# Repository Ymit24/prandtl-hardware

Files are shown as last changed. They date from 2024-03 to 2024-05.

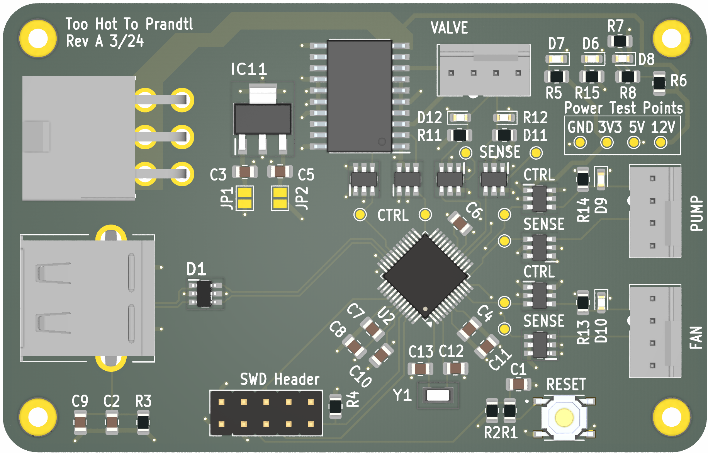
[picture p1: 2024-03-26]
pictures/ray_ortho_home_no_shadows.png

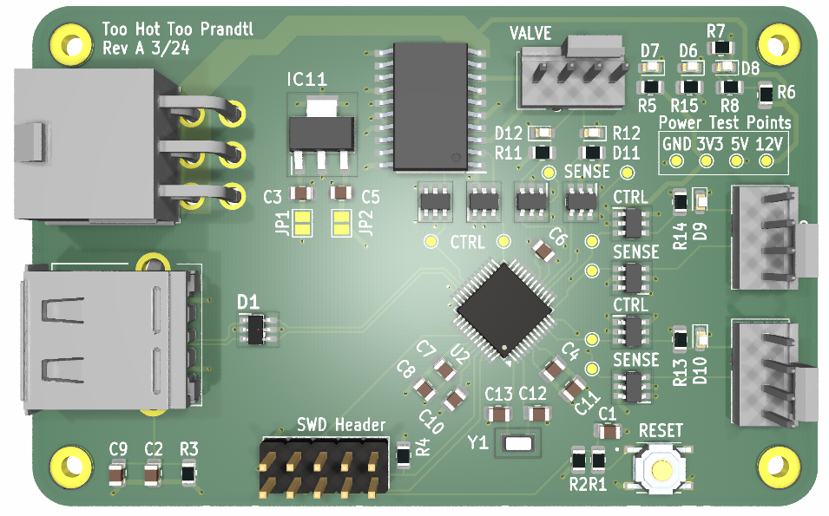
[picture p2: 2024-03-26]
pictures/raw_persp_home.png

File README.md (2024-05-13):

# ❄️🎛️ Too Hot To Prandtl Hardware

## About this repo
This repo contains all the hardware I designed for my undergraduate senior design project "Too Hot To Prandtl".

<!-- TABLE OF CONTENTS -->
<div>
  <h4>Table of Contents</h4>
  <ol>
    <li>
      <a href="#about-the-project">About The Project</a>
      <ul>
        <li><a href="#built-with">Built With</a></li>
      </ul>
    </li>
    <li><a href="#roadmap">Roadmap</a></li>
    <li><a href="#license">License</a></li>
    <li><a href="#contact">Contact</a></li>
  </ol>
</div>

## About the Project
My senior design project, "Too hot to prandtl", is a thermal management solution designed for heterogeniously packaged chips.
It is a fluid based cooler which leverages phase change to increase heat transfer.
Myself, along with four Mechnical Engineering students designed, simulated, fabricated, and tested this system.
As the teams sole Electrical Engineer, I wrote all the software and designed, ordered, assembled, and brought-up the custom embedded system's printed circuit board (PCB).
The software for this project is hosted in a seperate repository found [here](https://github.com/Ymit24/too-hot-to-prandtl-control-system/tree/main).



## Project Structure
This system is designed in KiCad. Any non-default symbols/footprints/models are located in the `lib/` directory and included in the custom symbols and footprints libraries.
Production files which were used for the prototype system are in the `production/` directory.

### Built With
- [KiCad](https://www.kicad.org), awesome free PCB designing tool!

## Roadmap
There are several design flaws in the first version of this system, all of which were able to be fixed in the lab so that the board was still operable.
Below are a few issues which I would address in a revision B, ordered from most severe to least.

- ESD protection diode is connected incorrectly. I misread the data sheet and connected the channels incorrectly.
- Serial wire debug header is both the wrong size/type and the footprint had a different pin labelling scheme than intended.
- Fan peripheral header needs power and ground connection.
- Use a single 8-bit/channel logic level shifter rather than eight individual 1-bit/channel shifters.
- Choose dimmer LEDs, the ones choosen are very bright.
- Fix typo in silkscreen for board name "Too Hot Too Prandtl" -> "Too Hot To Prandtl".

## License
This project uses the GNU General Purpose License (GPL). Basically, do whatever you want but you must open source any derivative work!

## Contact
My name is Christian Smith and you can contact me through my linked in [here](https://www.linkedin.com/in/christian-ryan-smith/).
As this was a senior design project which has now concluded, further work and support of this project will not continue.

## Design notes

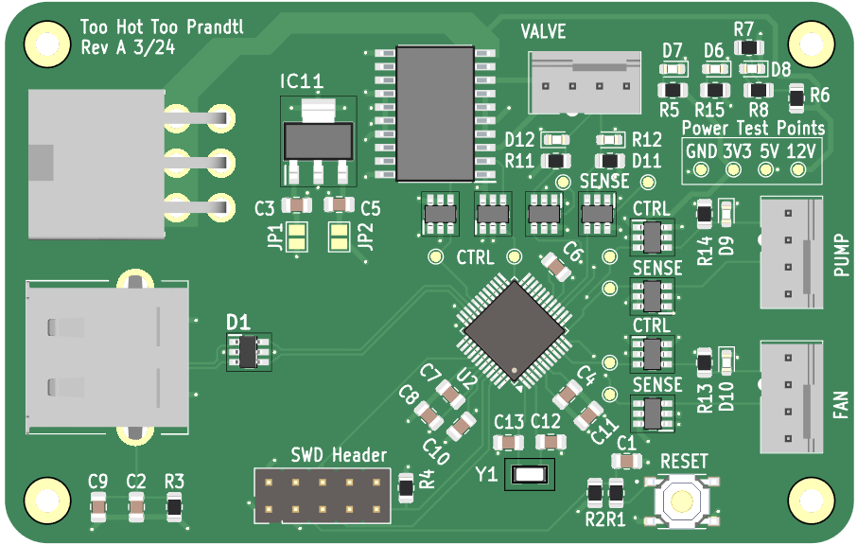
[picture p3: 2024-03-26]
pictures/style_ortho_home.png

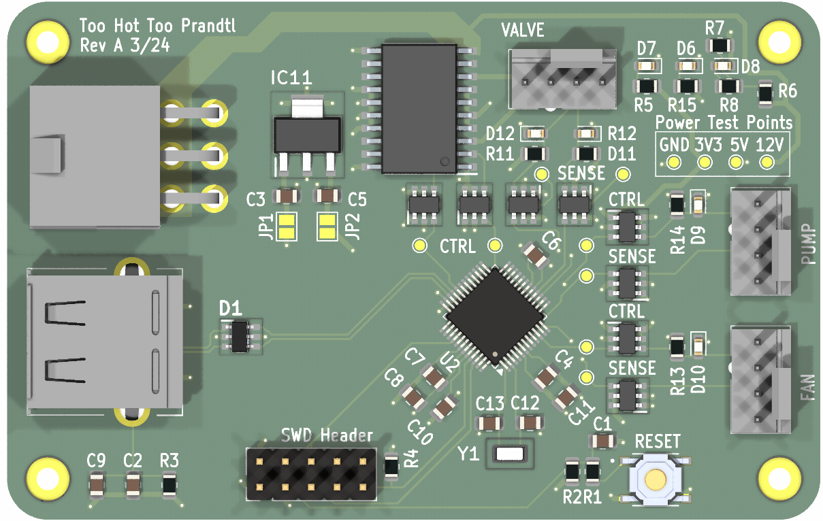
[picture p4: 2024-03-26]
pictures/ray_ortho_home_new.png

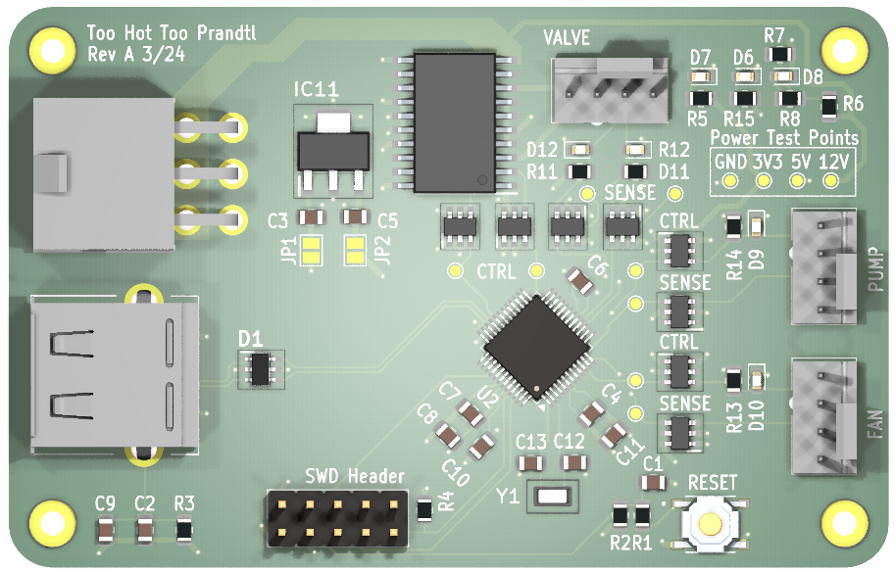
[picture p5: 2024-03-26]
pictures/ray_ortho_home.png

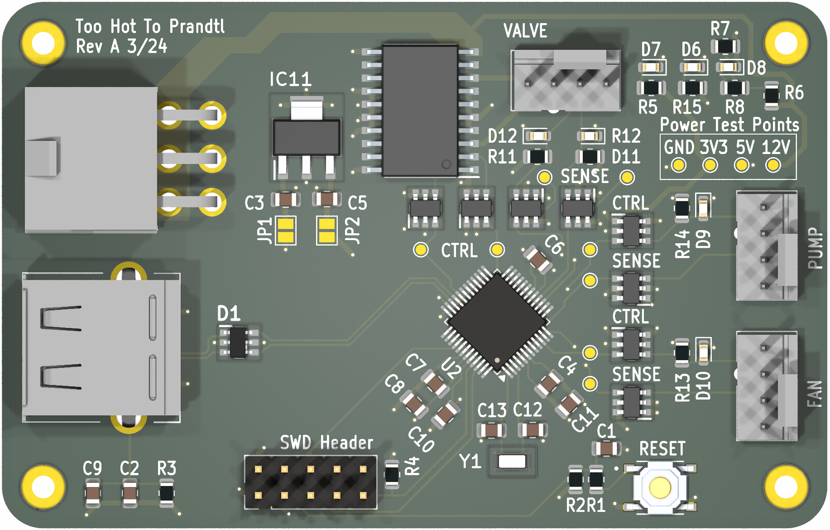
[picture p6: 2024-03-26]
pictures/ray_ortho_home_shadows.png

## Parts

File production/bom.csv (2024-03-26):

Designator | Footprint | Quantity | Value | LCSC Part #
C1, C4, C6, C7 | 0805 | 4 | 100n | C49678
C10, C11 | 0805 | 2 | 10u | C15850
C12, C13 | 0805 | 2 | 20p | C105173
C2, C9 | 0805 | 2 | 2.2n | C28260
C3 | 0805 | 1 | 470n | C13967
C5 | 0805 | 1 | 47u | C16780
C8 | 0805 | 1 | 1u | C307362
D1 | SOP95P275X110-6N | 1 | IP4234CZ6,125 | C455086
D10 | 0603 | 1 | FAN_PWM_IND | C2297
D11 | 0603 | 1 | VALVE_OPEN_IND | C2296
D12 | 0603 | 1 | VALVE_CLOSED_IND | C2296
D6 | 0603 | 1 | 5V_USB_PWR_IND | C2286
D7 | 0603 | 1 | 3v3_PWR_IND | C2286
D8 | 0603 | 1 | 12v_PWR_IND | C2286
D9 | 0603 | 1 | PUMP_PWM_IND | C2297
IC11 | SOT230P700X180-4N | 1 | LM3940IMP-3.3_NOPB | C140319
R1 | 0805 | 1 | 330 | C17630
R11, R12, R13, R14, R15 | 0805 | 5 | 200R | C17540
R2 | 0805 | 1 | 10k | C17414
R3 | 0805 | 1 | 1M | C17514
R4 | 0805 | 1 | 1k | C17513
R5 | 0805 | 1 | 51R | C17738
R6, R7 | 0805 | 2 | 470R | C17738
R8 | 0805 | 1 | 300R | C17617
S1 | SW_TS-1187A-B-A-B | 1 | TS-1187A-B-A-B | C318884
U2 | TQFP-48_7x7mm_P0.5mm | 1 | ATSAMD21G18A-A | C78624
Y1 | FC135327680KAA5 | 1 | 32.768kHz | C32346

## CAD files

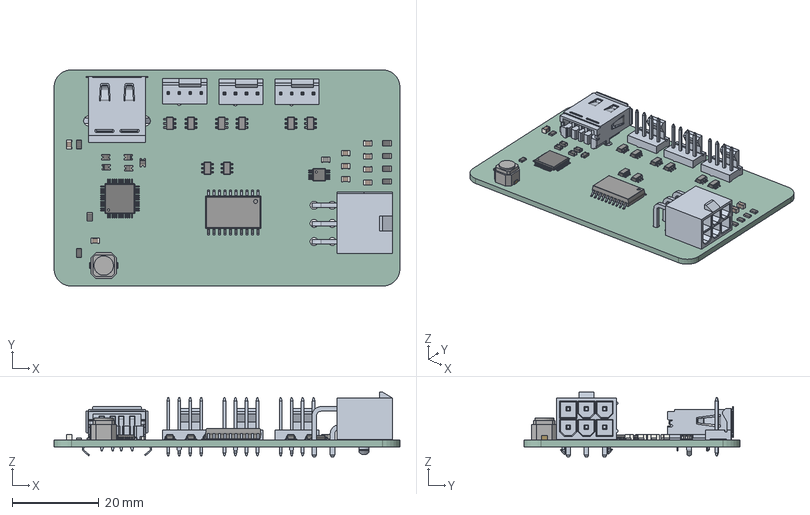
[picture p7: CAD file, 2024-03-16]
playground.step
80.0 x 50.0 x 15.0 mm
LinkGroup
R_0805_2012Metric x 7
C_0805_2012Metric x 9
TQFP_48_7x7mm_P05mm
DBV0006A_ASM x 8
L_0805_2012Metric
D_0805 x 5
ASSEMBLY
MSOP_10_3x3mm_P05mm
playground_PCB

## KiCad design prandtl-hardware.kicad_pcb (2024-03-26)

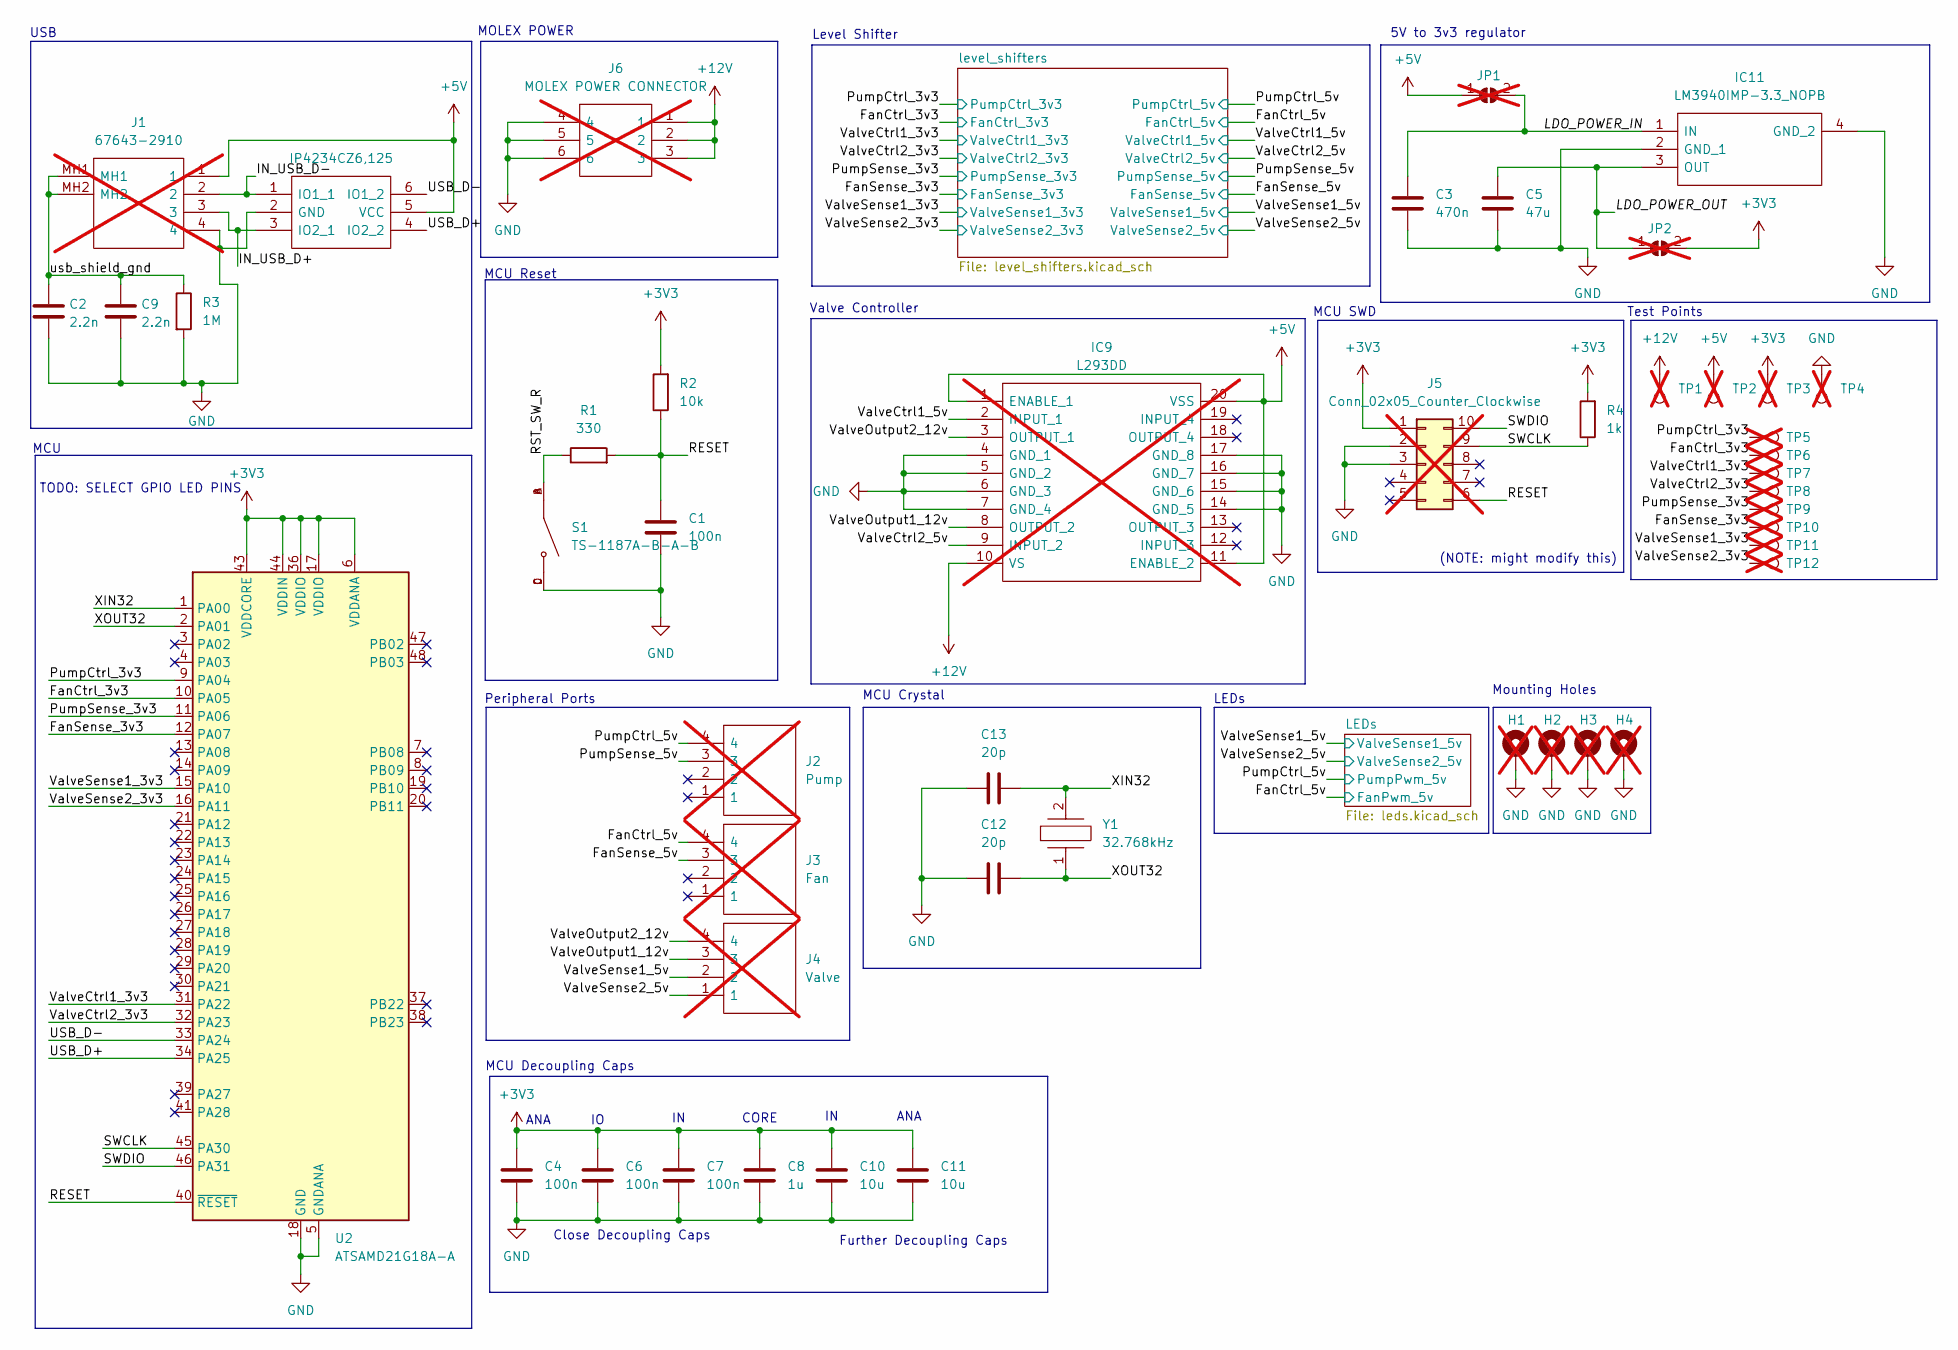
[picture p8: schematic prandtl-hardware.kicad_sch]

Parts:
C1, C4, C6, C7: 100n; C_0805_2012Metric; LCSC C49678
C2, C9: 2.2n; C_0805_2012Metric; LCSC C28260
C3: 470n; C_0805_2012Metric; LCSC C13967
C5: 47u; C_0805_2012Metric; LCSC C16780
C8: 1u; C_0805_2012Metric; LCSC C307362
C10, C11: 10u; C_0805_2012Metric; LCSC C15850
C12, C13: 20p; C_0805_2012Metric; LCSC C105173
D1: IP4234CZ6,125; SOP95P275X110-6N; Mouser Part Number 771-IP4234CZ6125
H1, H2, H3, H4: MountingHole_Pad; MountingHole_2.2mm_M2_Pad; not fitted
IC9: L293DD; SOIC127P1032X265-20N; Mouser Part Number 511-L293DD; not fitted
IC11: LM3940IMP-3.3_NOPB; SOT230P700X180-4N; Mouser Part Number 926-LM3940IMP3.3NOPB
J1: 67643-2910; 676432910; Mouser Part Number 538-67643-2910; not fitted
J2: Pump; 470531000; Mouser Part Number 538-47053-1000; not fitted
J3: Fan; 470531000; Mouser Part Number 538-47053-1000; not fitted
J4: Valve; 470531000; Mouser Part Number 538-47053-1000; not fitted
J5: Conn_02x05_Counter_Clockwise; PinHeader_2x05_P2.54mm_Vertical; not fitted
J6: MOLEX POWER CONNECTOR; 455580003; Mouser Part Number 538-45558-0003; not fitted
JP1, JP2: SolderJumper_2_Open; SolderJumper-2_P1.3mm_Open_Pad1.0x1.5mm; not fitted
R1: 330; R_0805_2012Metric; LCSC C17630
R2: 10k; R_0805_2012Metric; LCSC C17414
R3: 1M; R_0805_2012Metric; LCSC C17514
R4: 1k; R_0805_2012Metric; LCSC C17513
S1: TS-1187A-B-A-B; SW_TS-1187A-B-A-B; PARTREV A0; LCSC C318884
TP1, TP2, TP3, TP4, TP5, TP6, TP7, TP8, TP9, TP10, TP11, TP12: TestPoint; TestPoint_Pad_D1.0mm; not fitted
U2: ATSAMD21G18A-A; TQFP-48_7x7mm_P0.5mm; LCSC C78624
Y1: 32.768kHz; FC135327680KAA5; Mouser Part Number 732-532.7680KA-A5

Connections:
+3V3: C4.1, C6.1, C7.1, C8.1, C10.1, C11.1, J5.1, JP2.2 (B), R2.2, R4.2, TP3.1, U2.6 (VDDANA), U2.17 (VDDIO), U2.36 (VDDIO), U2.43 (VDDCORE), U2.44 (VDDIN); also elsewhere on the board
+5V: D1.5 (VCC), IC9.1 (ENABLE_1), IC9.11 (ENABLE_2), IC9.20 (VSS), J1.1, JP1.1 (A), TP2.1; also elsewhere on the board
+12V: IC9.10 (VS), J6.1, J6.2, J6.3, TP1.1; also elsewhere on the board
/FanCtrl_3v3: TP6.1, U2.10 (PA05); also elsewhere on the board
/FanCtrl_5v: J3.4; also elsewhere on the board
/FanSense_3v3: TP10.1, U2.12 (PA07); also elsewhere on the board
/FanSense_5v: J3.3; also elsewhere on the board
/IN_USB_D+: D1.3 (IO2_1), J1.3
/IN_USB_D-: D1.1 (IO1_1), J1.2
/LDO_POWER_IN: C3.1, IC11.1 (IN), JP1.2 (B)
/LDO_POWER_OUT: C5.1, IC11.3 (OUT), JP2.1 (A)
/PumpCtrl_3v3: TP5.1, U2.9 (PA04); also elsewhere on the board
/PumpCtrl_5v: J2.4; also elsewhere on the board
/PumpSense_3v3: TP9.1, U2.11 (PA06); also elsewhere on the board
/PumpSense_5v: J2.3; also elsewhere on the board
/RESET: C1.1, J5.6, R1.2, R2.1, U2.40 (~RESET)
/RST_SW_R: R1.1, S1.A, S1.B
/SWCLK: J5.9, R4.1, U2.45 (PA30)
/SWDIO: J5.10, U2.46 (PA31)
/USB_D+: D1.4 (IO2_2), U2.34 (PA25)
/USB_D-: D1.6 (IO1_2), U2.33 (PA24)
/ValveCtrl1_3v3: TP7.1, U2.31 (PA22); also elsewhere on the board
/ValveCtrl1_5v: IC9.2 (INPUT_1); also elsewhere on the board
/ValveCtrl2_3v3: TP8.1, U2.32 (PA23); also elsewhere on the board
/ValveCtrl2_5v: IC9.9 (INPUT_2); also elsewhere on the board
/ValveOutput1_12v: IC9.8 (OUTPUT_2), J4.3
/ValveOutput2_12v: IC9.3 (OUTPUT_1), J4.4
/ValveSense1_3v3: TP11.1, U2.15 (PA10); also elsewhere on the board
/ValveSense1_5v: J4.2; also elsewhere on the board
/ValveSense2_3v3: TP12.1, U2.16 (PA11); also elsewhere on the board
/ValveSense2_5v: J4.1; also elsewhere on the board
/XIN32: C13.2, U2.1 (PA00), Y1.2
/XOUT32: C12.2, U2.2 (PA01), Y1.1
/usb_shield_gnd: C2.1, C9.1, J1.MH1, J1.MH2, R3.1
GND: C1.2, C2.2, C3.2, C4.2, C5.2, C6.2, C7.2, C8.2, C9.2, C10.2, C11.2, C12.1, C13.1, D1.2 (GND), H1.1, H2.1, H3.1, H4.1, IC9.4 (GND_1), IC9.5 (GND_2), IC9.6 (GND_3), IC9.7 (GND_4), IC9.14 (GND_5), IC9.15 (GND_6), IC9.16 (GND_7), IC9.17 (GND_8), IC11.2 (GND_1), IC11.4 (GND_2), J1.4, J5.2, J5.3, J6.4, J6.5, J6.6, R3.2, S1.C, S1.D, TP4.1, U2.5 (GNDANA), U2.18 (GND), U2.35 (GND), U2.42 (GND); also elsewhere on the board

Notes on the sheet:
LEDs
Valve Controller
MCU Reset
Close Decoupling Caps
ANA
MOLEX POWER
TODO: SELECT GPIO LED PINS
MCU Decoupling Caps
Further Decoupling Caps
MCU Crystal
5V to 3v3 regulator
Mounting Holes
(NOTE: might modify this)
MCU SWD
USB
MCU
Level Shifter
Peripheral Ports
Test Points
CORE

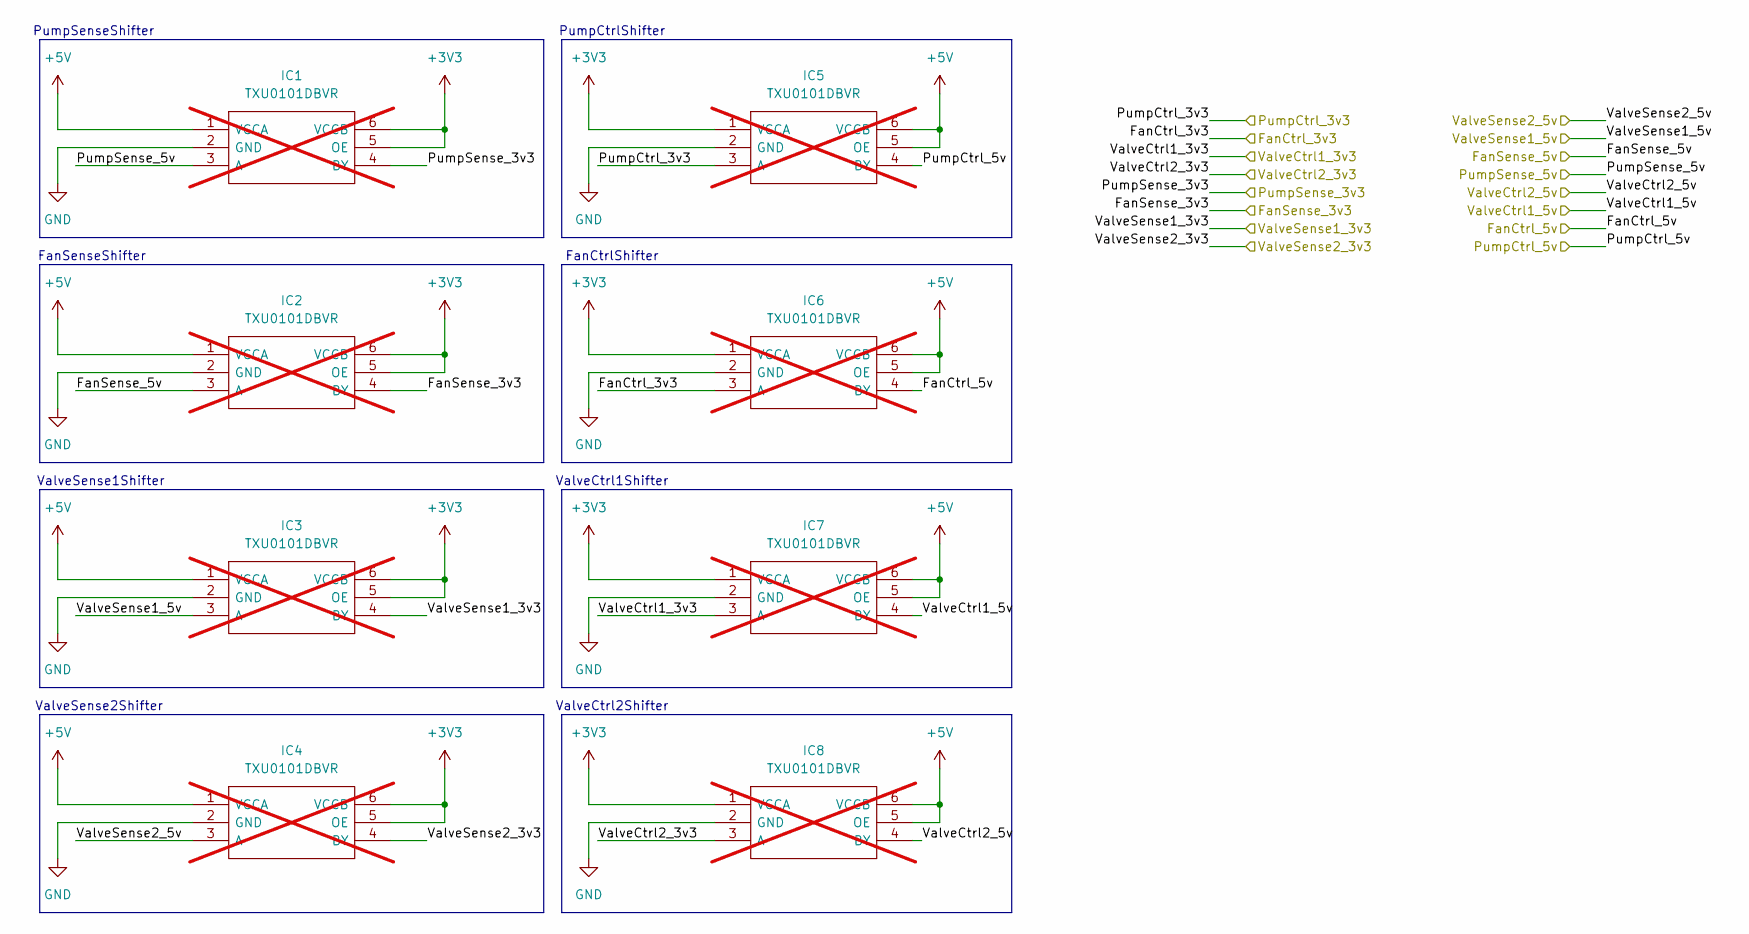
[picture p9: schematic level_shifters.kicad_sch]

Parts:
IC1, IC2, IC3, IC4, IC5, IC6, IC7, IC8: TXU0101DBVR; Mouser Part Number 595-TXU0101DBVR; not fitted

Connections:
+3V3: IC1.5 (OE), IC1.6 (VCCB), IC2.5 (OE), IC2.6 (VCCB), IC3.5 (OE), IC3.6 (VCCB), IC4.5 (OE), IC4.6 (VCCB), IC5.1 (VCCA), IC6.1 (VCCA), IC7.1 (VCCA), IC8.1 (VCCA); also elsewhere on the board
+5V: IC1.1 (VCCA), IC2.1 (VCCA), IC3.1 (VCCA), IC4.1 (VCCA), IC5.5 (OE), IC5.6 (VCCB), IC6.5 (OE), IC6.6 (VCCB), IC7.5 (OE), IC7.6 (VCCB), IC8.5 (OE), IC8.6 (VCCB); also elsewhere on the board
/FanCtrl_3v3: IC6.3 (A); also elsewhere on the board
/FanCtrl_5v: IC6.4 (BY); also elsewhere on the board
/FanSense_3v3: IC2.4 (BY); also elsewhere on the board
/FanSense_5v: IC2.3 (A); also elsewhere on the board
/PumpCtrl_3v3: IC5.3 (A); also elsewhere on the board
/PumpCtrl_5v: IC5.4 (BY); also elsewhere on the board
/PumpSense_3v3: IC1.4 (BY); also elsewhere on the board
/PumpSense_5v: IC1.3 (A); also elsewhere on the board
/ValveCtrl1_3v3: IC7.3 (A); also elsewhere on the board
/ValveCtrl1_5v: IC7.4 (BY); also elsewhere on the board
/ValveCtrl2_3v3: IC8.3 (A); also elsewhere on the board
/ValveCtrl2_5v: IC8.4 (BY); also elsewhere on the board
/ValveSense1_3v3: IC3.4 (BY); also elsewhere on the board
/ValveSense1_5v: IC3.3 (A); also elsewhere on the board
/ValveSense2_3v3: IC4.4 (BY); also elsewhere on the board
/ValveSense2_5v: IC4.3 (A); also elsewhere on the board
GND: IC1.2 (GND), IC2.2 (GND), IC3.2 (GND), IC4.2 (GND), IC5.2 (GND), IC6.2 (GND), IC7.2 (GND), IC8.2 (GND); also elsewhere on the board

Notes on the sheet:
ValveSense1Shifter
PumpCtrlShifter
ValveCtrl2Shifter
ValveSense2Shifter
FanCtrlShifter
PumpSenseShifter
ValveCtrl1Shifter
FanSenseShifter

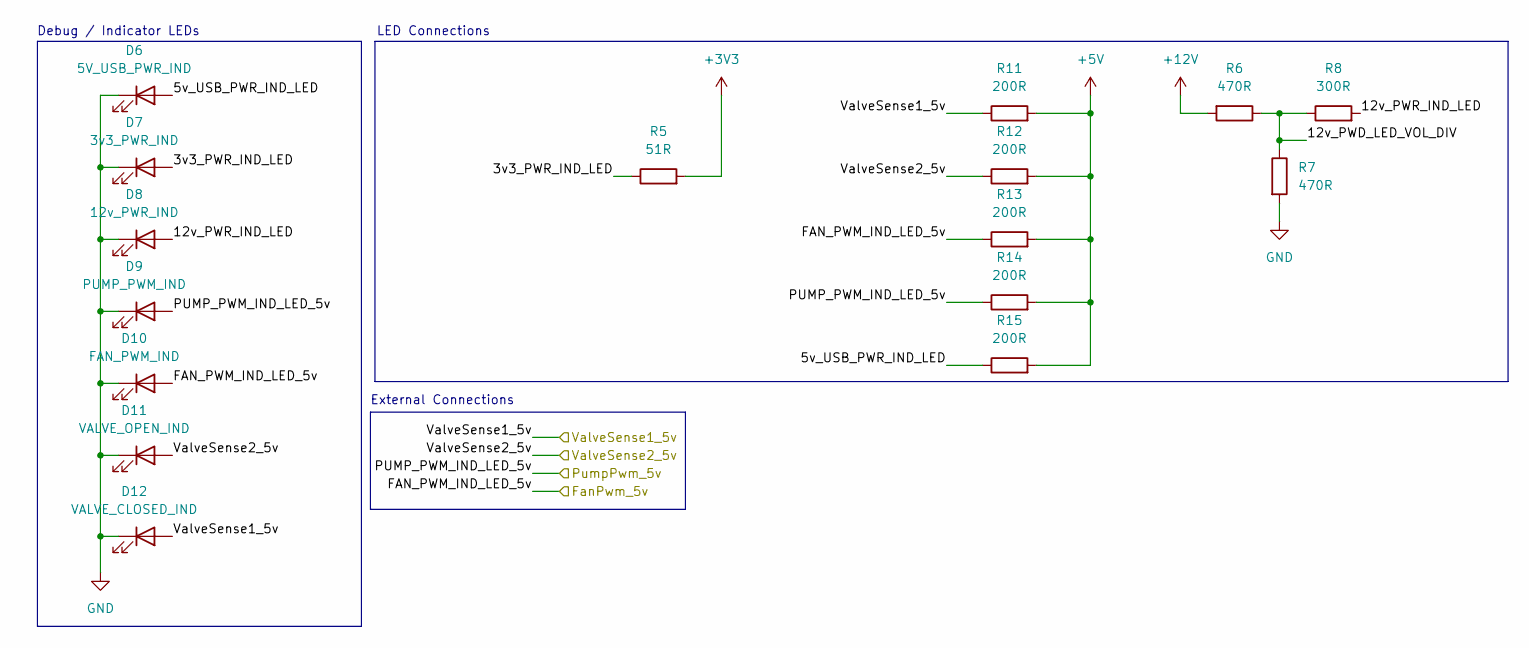
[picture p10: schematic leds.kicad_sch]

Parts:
D6: 5V_USB_PWR_IND; LED_0603_1608Metric; LCSC C2286
D7: 3v3_PWR_IND; LED_0603_1608Metric; LCSC C2286
D8: 12v_PWR_IND; LED_0603_1608Metric; LCSC C2286
D9: PUMP_PWM_IND; LED_0603_1608Metric; LCSC C2297
D10: FAN_PWM_IND; LED_0603_1608Metric; LCSC C2297
D11: VALVE_OPEN_IND; LED_0603_1608Metric; LCSC C2296
D12: VALVE_CLOSED_IND; LED_0603_1608Metric; LCSC C2296
R5: 51R; R_0805_2012Metric; MFR.Part # 0805W8F510JT5E; LCSC C17738
R6: 470R; R_0805_2012Metric; MFR.Part # 0805W8F4700T5E; LCSC C17738
R7: 470R; R_0805_2012Metric; LCSC C17738
R8: 300R; R_0805_2012Metric; MFR.Part # 1206W4F3000T5E; LCSC C17617
R11, R12, R13, R14, R15: 200R; R_0805_2012Metric; MFR.Part # 0805W8F200JT5E; LCSC C17540

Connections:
+3V3: R5.2; also elsewhere on the board
+5V: R11.2, R12.2, R13.2, R14.2, R15.2; also elsewhere on the board
+12V: R6.2; also elsewhere on the board
/FanCtrl_5v: D10.2 (A), R13.1; also elsewhere on the board
/LEDs/3v3_PWR_IND_LED: D7.2 (A), R5.1
/LEDs/5v_USB_PWR_IND_LED: D6.2 (A), R15.1
/LEDs/12v_PWD_LED_VOL_DIV: R6.1, R7.1, R8.1
/LEDs/12v_PWR_IND_LED: D8.2 (A), R8.2
/PumpCtrl_5v: D9.2 (A), R14.1; also elsewhere on the board
/ValveSense1_5v: D12.2 (A), R11.1; also elsewhere on the board
/ValveSense2_5v: D11.2 (A), R12.1; also elsewhere on the board
GND: D6.1 (K), D7.1 (K), D8.1 (K), D9.1 (K), D10.1 (K), D11.1 (K), D12.1 (K), R7.2; also elsewhere on the board

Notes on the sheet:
Debug / Indicator LEDs
External Connections
LED Connections

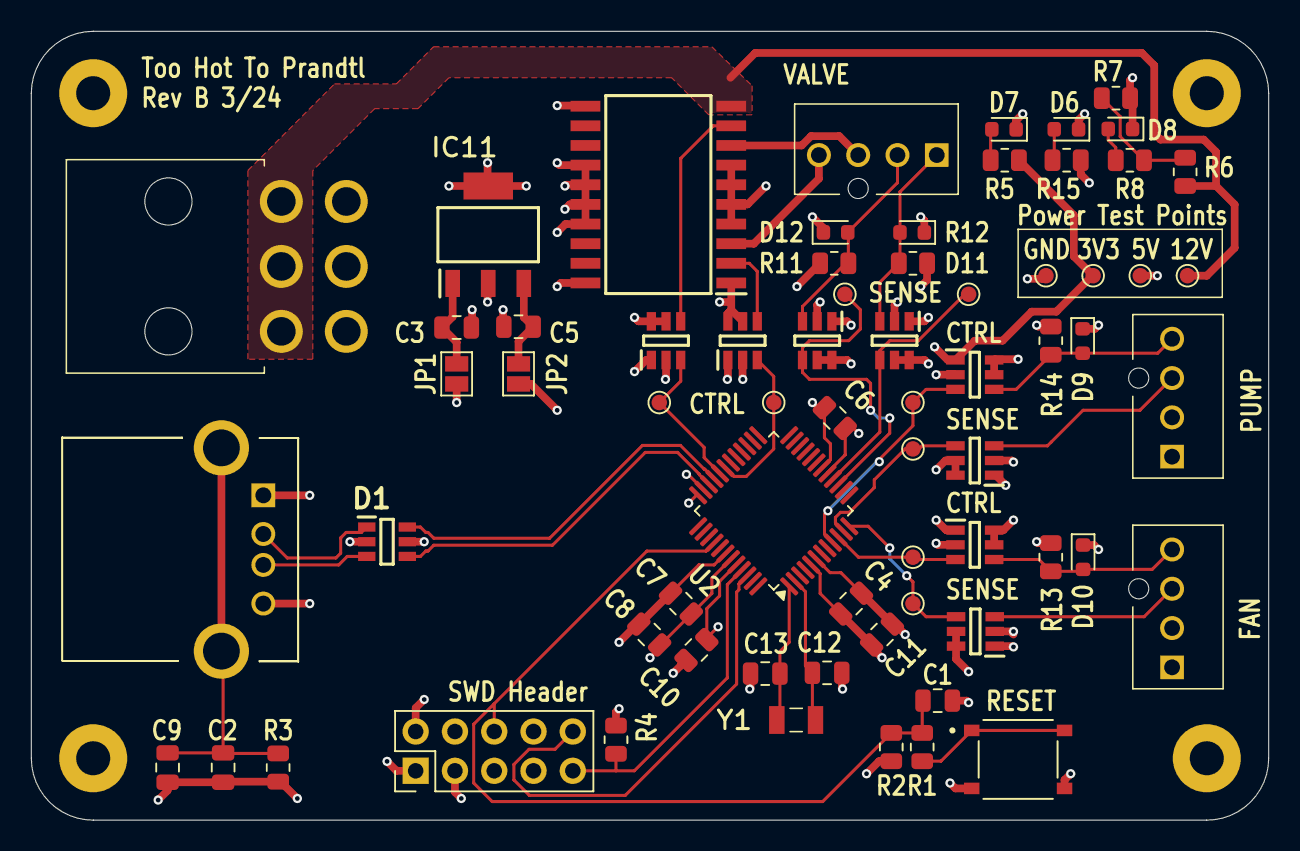
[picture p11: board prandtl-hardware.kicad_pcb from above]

Board: 4 copper layers, 80.0 x 51.0 mm, 71 parts (0 on the bottom side), 39 nets.

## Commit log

2024-02-25 did basic routing. Still missing some parts.
    [playground.kicad_pcb, playground.kicad_sch]
2024-03-16 storing local changes.
    [playground.step]
2024-03-20 saving progress
    [BOM-playground.csv, level_shifters.kicad_sch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]
2024-03-20 Added LEDs and testpoints
    [leds.kicad_sch, playground.kicad_pcb, playground.kicad_sch]
2024-03-21 removed jumpers
    [playground.kicad_pcb, playground.kicad_sch]
2024-03-21 Changed board size to 80x80mm
    [playground.kicad_pcb]
2024-03-22 Updated layout and schem
    [leds.kicad_sch, playground.kicad_pcb, playground.kicad_sch]
2024-03-23 Layout of indicator LEDs. Shrank design space
    [leds.kicad_sch, playground.kicad_pcb, playground.kicad_sch]
2024-03-23 Reduced board size
    [playground.kicad_pcb]
2024-03-23 Initial Routing
    [playground.kicad_pcb]
2024-03-23 Completed intial 2-layer routing.
    [playground.kicad_pcb]
2024-03-23 Initial Layout
    [leds.kicad_sch, playground.kicad_pcb, playground.kicad_sch]
2024-03-23 Fixed board outline
    [playground.kicad_pcb]
2024-03-24 Layout and Route of 4 layer version complete.
    [playground.kicad_pcb, playground.kicad_sch]
2024-03-24 Modified layout. Added more silkscreen.
    [playground.kicad_pcb, playground.kicad_sch]
2024-03-24 Fixed all DRC issues
    [playground.kicad_pcb]
2024-03-24 Small part substitutions. Working on BOM
    [bom.csv, designators.csv, playground.kicad_pcb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]
2024-03-26 Added all part numbers
    [leds.kicad_sch, playground.kicad_pcb, playground.kicad_sch]
2024-03-26 Prepped for production.
    [bom.csv, designators.csv, level_shifters.kicad_sch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]
2024-03-26 Version exported for production.
    [playground.kicad_pcb, positions.csv]
2024-03-26 Took pictures of PCB
    [playground.kicad_pcb]
2024-03-26 Cleaned up project files
    [bom.csv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]
2024-03-26 Fixed spelling of 'Too hot _to_ prandtl'. Now rev B
    [playground.kicad_pcb]
2024-03-26 (part of last commit)
    [playground.kicad_pcb]
2024-05-13 renamed project
    [BOM-playground.csv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]
2024-05-13 removed old power regulator files
    [power_regulation.kicad_sch]
